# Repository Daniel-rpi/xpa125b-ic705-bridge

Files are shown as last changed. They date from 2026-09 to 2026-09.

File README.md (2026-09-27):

# IC-705 ↔ Xiegu XPA125B via TTGO Bluetooth-Bridge

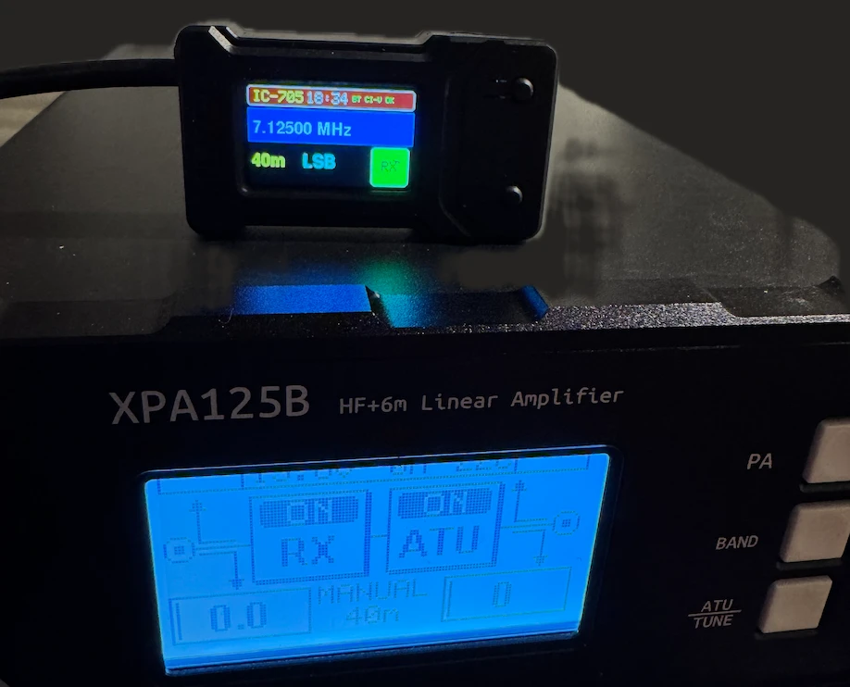
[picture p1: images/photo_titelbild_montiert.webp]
Fertiges Modul auf der XPA125B


Ein LilyGO **TTGO T-Display v1.1** (ESP32) verbindet sich per **Bluetooth
Classic (CI-V-over-SPP)** mit einem Icom **IC-705** und steuert darüber eine
nachgeschaltete Xiegu **XPA125B**-Endstufe (100 W HF-Verstärker) vollautomatisch:
Bandumschaltung, PTT und – seit Kurzem – eine softwareseitige ALC-basierte
Schutzschaltung, die eingreift, bevor die PA in ihre eigene harte
Fehlerabschaltung läuft.

Kein Kabelsalat zwischen 705 und PA, kein manuelles Bandwechseln an der PA, und
eine grobe, aber wirksame Warnstufe vor Übersteuerung – bei einem Funkgerät, das
selbst gar keine passende ACC-Buchse für so eine PA hat.

*(English: An ESP32 board bridges an Icom IC-705 (Bluetooth CI-V) to a Xiegu
XPA125B HF amplifier — automatic band switching, PTT, and a software ALC-based
overdrive protection layer. See [docs/alc-protection.md](docs/alc-protection.md)
for a full English write-up of the protection logic.)*

## ⚠️ Sicherheitshinweise (bitte vor dem Nachbau lesen)

- **≥ 3,2 V am PTT-Eingang der XPA125B zerstört deren internen Prozessor
  dauerhaft** (laut offiziellem Handbuch). Der PTT-Ausgang des TTGO läuft daher
  ausschließlich über eine galvanische Trennung (Optokoppler bzw. MOSFET-gegen-GND,
  siehe unten) – niemals GPIO26 direkt an die PA anschließen.
- Diese Firmware sendet zur reinen Anzeige (Frequenz/Modus/TX-Status/Uhrzeit)
  **ausschließlich CI-V-Lesebefehle**. Echte Sende-Kommandos (Leistung setzen,
  Modus setzen, PTT) gibt es nur in der Tune-Sequenz (Taster) und der
  ALC-Schutzfunktion – beide sind im Quellcode ausführlich kommentiert.
- Alle hier beschriebenen Werte (Bandspannungen, PTT-Pegel, ALC-Schwellen) sind
  **an einem konkreten IC-705 und einer konkreten XPA125B gemessen**. Vor dem
  Anschließen an eigene Hardware selbst nachmessen, nicht blind übernehmen.
- Kein Ersatz für die Schutzabschaltung der PA selbst – nur eine zusätzliche,
  frühere Warnstufe.
- Nachbau/Nutzung auf eigene Verantwortung.

## Basiert auf / Danke an

Dieses Projekt wäre ohne die Vorarbeit von **DL1BZ** nicht in dieser Form
entstanden:

- [dl1bz/ESP32-IC705BT-PA](https://github.com/dl1bz/ESP32-IC705BT-PA) – das
  ursprüngliche Konzept (ESP32 + Bluetooth-CI-V + Optokoppler-PTT + PWM/RC-Band-
  spannung für eine XPA125B), inklusive Forks von
  [PE1OFO](https://github.com/PE1OFO/IC-705-BlueTooth-Controller) und
  [DK8HC](https://github.com/dk8hc/IC-705-BlueTooth-Controller).

**Wichtig, damit klar ist, was wovon abstammt:** Die hier veröffentlichte
Firmware ist ein **komplett eigenständig geschriebener Sketch** (kein Codeauszug
aus den obigen Repos, keine `CIVmasterLib`-Abhängigkeit) – die Übernahme betrifft
das **Konzept und einzelne kalibrierte Werte**: die Verdrahtung
GPIO26→PTT/GPIO27→Bandspannung, die Bandspannungstabelle aus dem Xiegu-Handbuch
und die daraus abgeleitete Lastkorrektur (`corrMv` in `firmware/bands.h`) sind
1:1 aus `z_userprog.ino` von DL1BZ übernommen. Alles Weitere (TFT-Anzeige,
Uhrzeit/UTC, Tune-Sequenz mit FB/NG-Bestätigung, ALC-Auslesung samt
Schutzschaltung, das komplette PMR-171-BLE-Modul, die Daughterboard-Platine) ist
eigene Arbeit dieses Projekts.

## Fotos

| Rückseite (fertiges Modul) | Draufsicht (fertiges Modul) | Innenansicht |
|---|---|---|
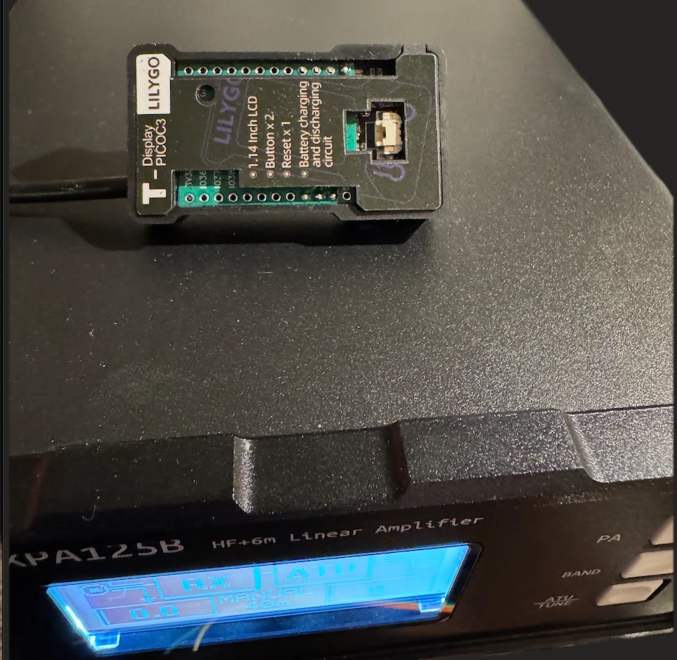
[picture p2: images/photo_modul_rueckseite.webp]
Rückseite des fertigen Moduls
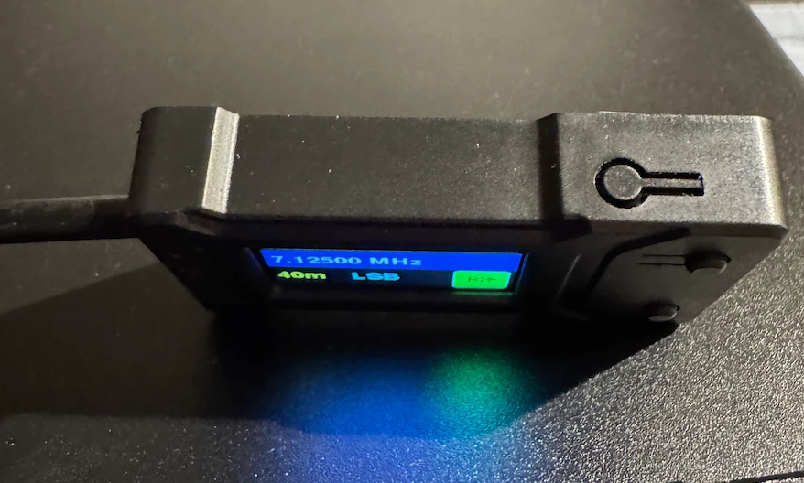
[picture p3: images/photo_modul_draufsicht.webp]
Draufsicht des fertigen Moduls
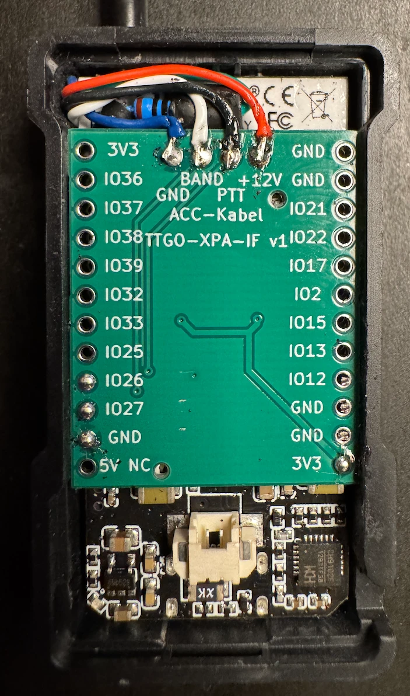
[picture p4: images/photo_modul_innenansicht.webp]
Innenansicht des fertigen Moduls
|  |  |  |

## Hardware

### Übersicht

```
IC-705 ──(Bluetooth Classic, CI-V-over-SPP)──> TTGO T-Display v1.1 (ESP32)
                                                     │  GPIO26 (PTT, über Opto/MOSFET gegen GND)
                                                     │  GPIO27 (PWM → RC 470Ω/22µF → Bandspannung)
                                                     │  GPIO36 (ADC, über 220Ω ← ALC-Ausgang, Pin 4)
                                                     ▼
                                        Xiegu XPA125B – ACC-Buchse (6-pol. Mini-DIN)
                                        Pin 1 = +12…14,5V (Versorgung der Platine) ⚠️ siehe unten
                                        Pin 2 = PTT (≥3,2V = Prozessorschaden!)
                                        Pin 3 = Bandspannung
                                        Pin 4 = ALC-Ausgang (~1–4V, invertiert)
                                        Pin 6 = GND
```

> **⚠️ ACC-Pin 1 ist im offiziellen Xiegu-Handbuch als N/C (nicht belegt)
> dokumentiert – liegt bei unserem (unmodifizierten, werksseitigen) Exemplar
> aber real die volle Versorgungsspannung der PA an** (gemessen ~12,85 V bei
> eingeschalteter PA am Netzteil, skaliert entsprechend mit der extern
> angelegten 12–14,5 V-Spannung). Genau das macht die eigene Stromversorgung
> des TTGO über die ACC-Buchse erst möglich, ohne ein zweites Netzteil oder
> einen Eingriff in die PA. Diese Diskrepanz zwischen Handbuch und Realität hat
> uns selbst lange beschäftigt (mehrere Diskussionsrunden, bis wir es am Ende
> direkt mit dem Multimeter durchgemessen haben) – **vor dem Nachbau unbedingt
> selbst am eigenen Gerät nachmessen**, statt sich auf das Handbuch *oder*
> diese Notiz zu verlassen. Xiegu könnte diese Pinbelegung in einer anderen
> Fertigungscharge/Hardwarerevision jederzeit ändern, ohne das zu
> dokumentieren – schließlich war sie nie offiziell zugesichert.

Das TTGO bezieht seine eigene 3,3-V-Versorgung direkt aus dieser
(inoffiziellen, aber real anliegenden) ACC-Pin-1-Spannung der PA (isolierter
DC/DC-Wandler bzw. Buck-Regler auf dem Daughterboard, siehe `hardware/`) –
**kein separates USB-Netzteil nötig, aber USB und PA-Strom dürfen nicht
gleichzeitig anliegen** (kein Akku auf der Platine, zwei Spannungsquellen
würden sich gegenseitig stören).

### Eigene SMD-Platine (Daughterboard)

Statt der Verkabelung frei fliegend aufzubauen: ein fertig geroutetes,
2-lagiges Daughterboard, das exakt auf die Stiftleisten des TTGO T-Display v1.1
gesteckt wird (Pin-Raster 1:1 aus der offiziellen LilyGO-Eagle-Bibliothek
übernommen), inkl. isoliertem Step-Down-Wandler, PTT-Schaltung und
RC-Filter für die Bandspannung.

- **[hardware/DESIGN.md](hardware/DESIGN.md)** – vollständige Bauteilliste,
  Netzliste, Layout-Vorgaben, Inbetriebnahme-Checkliste
- **[hardware/BESTELLUNG.md](hardware/BESTELLUNG.md)** – Schritt-für-Schritt
  JLCPCB-Bestellanleitung
- **`hardware/kicad/`** – fertig geroutetes KiCad-Projekt (DRC-geprüft)
- **`hardware/gerber/`** – Gerber + BOM + CPL, fertig für den JLCPCB-Upload
- **`images/`** – Renderansichten sowie reale Fotos des bestückten Boards

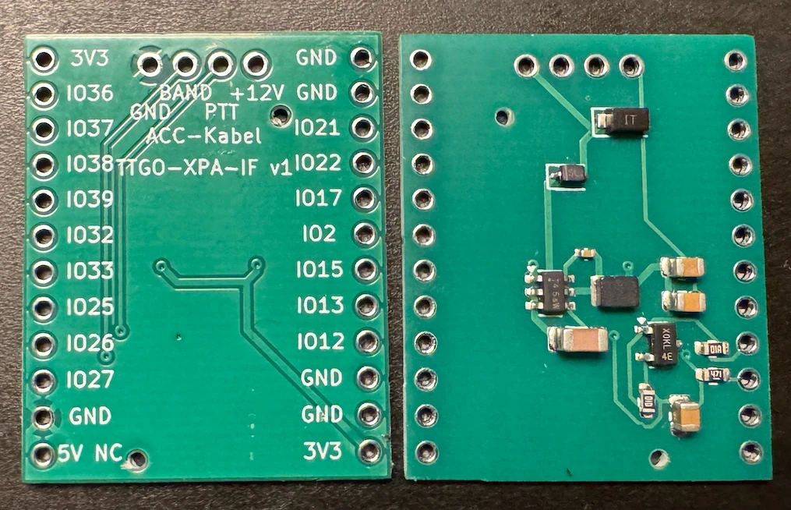
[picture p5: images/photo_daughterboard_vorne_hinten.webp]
Daughterboard: Vorder- und Rückseite


Die im finalen PCB-Entwurf verwendete PTT-Schaltung (N-MOSFET gegen GND) ist
eine bewusste, im Prototyp **nicht** getestete Vereinfachung gegenüber dem
ursprünglich verifizierten Optokoppler-Aufbau – Details und Begründung in
`hardware/DESIGN.md`. Der Optokoppler-Aufbau selbst ist am realen Gerät
vollständig getestet (siehe unten).

## Firmware

`firmware/ttgo_xpa_bridge.ino` (+ `bands.h`, `tft_setup.h`) – ein einziger
Arduino-Sketch für das TTGO T-Display v1.1 (Board-Definition:
`esp32:esp32:lilygo_t_display`, Arduino-ESP32-Core 3.x).

### Funktionen

- **Live-Anzeige** auf dem eingebauten TFT: Frequenz, Modulationsart, Band,
  RX/TX-Status, Uhrzeit (lokal + UTC, aus dem 705 ausgelesen), S-Meter.
- **Automatische Bandumschaltung** der XPA125B passend zur 705-Frequenz (PWM →
  RC-Tiefpass → Bandspannung, Tabelle inkl. Lastkorrektur in `bands.h`).
- **PTT-Durchschaltung** – der 705 meldet TX per CI-V-Broadcast/FastPTT-Push,
  das TTGO schaltet die PA-PTT-Leitung synchron mit.
- **Tune-Taster** (oberer Button, Mehrfachklick = längere Haltezeit): setzt
  kurzzeitig Leistung + Modus (FM statt CW – siehe Kommentar im Code, PTT-only
  erzeugt in CW keinen Träger), keyt den XPA125B-eigenen Antennentuner, stellt
  danach den Ausgangszustand wieder her. Jeder Schritt wartet auf eine
  FB(OK)/FA(NG)-Bestätigung; bei Fehlschlag Eskalation bis zur kompletten
  Geräteabschaltung (Cmd `18 00`).
- **ALC-Schutzschaltung** (neu, 2026-09-27) – siehe
  **[docs/alc-protection.md](docs/alc-protection.md)** für die volle
  Herleitung, Kalibrierdaten und Begründung, warum ein einfacher gleitender
  Mittelwert dafür nicht ausreicht.
- **Persistentes ALC/Leistungs-Logging** auf SPIFFS (überlebt den
  USB/PA-Stromwechsel, den ein reiner RAM-Puffer nicht überlebt hätte).
- **Zweiter Funkgeräte-Modus (PMR-171, Bluetooth LE)** – per langem Tastendruck
  umschaltbar (in NVS/`Preferences` persistiert). Eigenständiges Protokoll
  (BLE GATT statt Classic SPP), teilt sich aber Anzeige/GPIO-Grundgerüst mit dem
  705-Modus. Die ALC-Schutzschaltung ist **bewusst 705-spezifisch** und bleibt
  in diesem Modus inaktiv.
- **Automatischer Bluetooth-Reconnect**: das Board ist gleichzeitig
  BT-Server (nimmt Verbindungen vom 705 an) und -Master (verbindet sich aktiv
  zu bereits gekoppelten Geräten) – deckt sowohl "705 verbindet sich selbst"
  als auch "705 hat die Verbindung verloren, TTGO holt sie aktiv zurück" ab.

### Serial-Kommandos (USB, 115200 Baud, nur wenn USB angeschlossen – siehe
Sicherheitshinweis oben zur PA-Stromversorgung)

| Kommando | Wirkung |
|---|---|
| `dbg on` / `dbg off` | rohe CI-V-Frames auf der Konsole mitloggen |
| `fastptt on` | fastPTT-Push (`24 00 00 01`) aktivieren |
| `txpoll <ms>` | Poll-Intervall für den TX-Status |
| `band <name\|zero\|auto>` | Bandspannung manuell fixieren/automatisch |
| `alclog dump` / `clear` / `status` | ALC/Leistungs-Log (SPIFFS) auslesen/löschen/Status |
| `alcprotect on` / `off` | Schutzschaltung ohne Neuflashen de-/aktivieren |

### Flashen

```bash
arduino-cli core install esp32:esp32
arduino-cli compile --fqbn esp32:esp32:lilygo_t_display firmware/ttgo_xpa_bridge.ino
arduino-cli upload -p /dev/ttyXXX --fqbn esp32:esp32:lilygo_t_display firmware/ttgo_xpa_bridge.ino
```

Getestet mit Arduino-ESP32-Core 3.3.11.

## Status

- **Optokoppler-Prototyp (frei verdrahtet):** live an der echten XPA125B
  verifiziert – Bandumschaltung, PTT, Tune-Sequenz, ALC-Auslesung und die
  Schutzschaltung wurden alle mit echter Hardware getestet.
- **SMD-Daughterboard (MOSFET-Variante):** gefertigt, bestückt und am realen
  Gerät montiert (siehe Fotos oben) – zeigt live Frequenz/Modus/RX-Status vom
  705. Die PTT-Schaltung dieser Variante ist damit im Aufbau bestätigt; ein
  vollständiger, ausführlicher Sende-Test steht als Nächstes an (siehe
  `hardware/DESIGN.md`).
- **ALC-Schutzschaltung:** live getestet in FM (Kollapspunkt sauber erkannt)
  und SSB (vierstufige automatische Rückregelungs-Kaskade beobachtet, hat einen
  drohenden PA-Fehlerabschaltung erfolgreich verhindert).

## Lizenz

Eigener Code (Firmware, PCB-Design) unter [MIT-Lizenz](LICENSE). Die in
`firmware/bands.h` übernommene Bandspannungs-/Lastkorrekturtabelle stammt aus
DL1BZs `z_userprog.ino` (siehe Danke-Abschnitt) – bitte bei Weiterverwendung
dieser konkreten Werte entsprechend referenzieren.

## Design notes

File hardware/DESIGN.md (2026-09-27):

# TTGO ↔ XPA125B – SMD-Platine (Entwurfspaket für EasyEDA / JLCPCB)

Stand 2026-09-18. Grundlage: die **am 2026-09-18 an der echten XPA125B verifizierte** Prototyp-Schaltung
(4N25 + RC + isolierter DC/DC), ergänzt um zwei bewusste Änderungen (siehe „Abweichungen vom Prototyp").
Alle Teilenummern/Bestände/Gebührenklassen wurden am 2026-09-18 live gegen die JLC-Teiledatenbank
(jlcsearch.tscircuit.com, Felder `is_basic`/`is_preferred`/`stock`) geprüft – vor der Bestellung im JLC-Warenkorb
nochmal gegenchecken.

## Bauform (Nutzervorgabe 2026-09-18): Daughter-Board direkt auf den TTGO-Stiftleisten
Kleine Platine mit **genau dem Pin-Raster des TTGO T-Display v1.1** (2 Reihen à 12 Pins, 2,54 mm Raster, Reihenabstand
22,86 mm). Sie wird von hinten auf die Stiftleisten des TTGO gesteckt und auf der Außenseite verlötet - optisch ein eng
anliegendes Huckepack-Board. Maße/Koordinaten stammen aus der **offiziellen LilyGO-Eagle-Bibliothek**
(`TTGO-TDisplay_LilyGO_official.lbr`, Package `TTGO-T-DISPLAY-OL`), nicht aus Schätzungen:
- **Platine 25,89 × 31,94 mm** (0,4 mm je Seite breiter als der TTGO, damit die Pads ≥ 0,7 mm Randabstand haben - JLC trennt bei der
  Bestückung Randstreifen per V-Ritz und verlangt dafür ca. 0,4 mm; Länge = die 12 Pins + je 2,0 mm Rand), 0,8 mm, 2 Lagen.
- Pads: Bohrung 1,0 mm, **Pad-Ø 1,6 mm** (bei 1,78 mm läge der Kupferrand nur 0,22 mm von der Platinenkante, JLC will ≥ 0,3 mm;
  mit 1,6 mm sind es 0,31 mm).
- **Alle 24 Pads** liegen an den TTGO-Positionen (Tabelle in `ttgo_daughterboard_pads.csv`, Vorschau `board_preview.svg`).
  **Nur vier Pads sind mit der Schaltung verbunden**, alle anderen sind reine Lötaugen ohne Netz:

| TTGO-Pin | Reihe | Position (x / y in mm ab Platinen-Ecke unten links, USB-C-Ende unten) | Netz |
|---|---|---|---|
| 3V3 (`3V3_0`) | links | 1,11 / 2,00 | `3V3` (Ausgang des Bucks) |
| GND (`GND_4`) | rechts | 23,97 / 4,54 | `GND` |
| GPIO27 | rechts | 23,97 / 7,08 | `G27` (Bandspannung) |
| GPIO26 | rechts | 23,97 / 9,62 | `G26` (PTT) |
| **5V** | rechts | 23,97 / 2,00 | **NICHT verbinden** (direkt neben GND_4 - Kupfer-Abstand beachten) |

- **Alle vier Signalpads liegen in der rechten Reihe** dicht beieinander (y = 2,0 … 9,6), 3V3 gegenüber links unten.
- **Freie Zone für hohe Bauteile:** Mitte zwischen den Reihen, **y = 7,1 … 14,7 mm** (zwischen den Pads GPIO27 und GPIO33),
  x ≈ 4,2 … 20,9 mm. Auf dem Rückseitenfoto des TTGO ist genau dieser Bereich weitgehend unbestückt (Flash-IC ≈ 1,8 mm und
  die Tantal-Elkos sitzen an den Rändern/im USB-Bereich). Dorthin C1 (1206) und L1; niedrige Teile dürfen auch woanders hin.
- **J1 (ACC-Kabel)**: 4 Lötpads im 2,54-mm-Raster am Displayende der Platine, Vorschlag x = 8,74 / 11,28 / 13,82 / 16,36 bei
  y = 29,5 (Reihenfolge `+12V`, `PTT`, `BAND`, `GND` = ACC-Pin 1, 2, 3, 6). Die Kabel gehen so **nach oben weg, nicht am
  USB-C-Anschluss vorbei**.
- **Bestückungsseite = Richtung TTGO (Nutzerentscheidung 2026-09-18):** Stiftleisten-Kunststoffkörper sind „etwas mehr als 2,5 mm"
  hoch, das ist der Spalt zwischen TTGO-Rückseite und Board. Höhenbudget der Bauteile (Spalt 2,5 mm): C1 1206 ≈ 1,6 mm, U1/L1/D/Q1
  ≈ 1,0-1,1 mm, 0805 ≈ 1,25 mm, 0603/0402 < 1 mm. Auf der TTGO-Rückseite sind laut Produktfoto (mm-Raster über das Bild gelegt)
  **nur der Flash-IC (≈ 1,75 mm, Frontansicht x = 1,9-7,3 / y = 4,6-14,6 mm) und die Tantal-Elkos am USB-Ende (y < 2,2 mm)** hoch;
  dort sitzt kein Bauteil des Daughter-Boards. Der QFN (≈ 0,9 mm, x = 8,9-15,5 / y = 18,5-25 mm) und die Kleinteile bleiben unter
  1,25 + 0,9 < 2,5 mm. **Beim ersten Aufstecken trotzdem Probe-Sitz prüfen** (Foto-Ablesung ist eine Näherung).
- Aus den KiCad-Daten: Board wird auf der **Außenseite (B.Cu)** nur verlötet - dort GND-Fläche, PTT/BAND-Langstrecken, Beschriftung
  der TTGO-Pins (gespiegelt, damit sie von außen lesbar ist).

## ⚠ Der eine Punkt, der gegen „keine Aufpreis-Teile" läuft
Die 3,3-V-Versorgung aus den ~12,85 V der ACC-Pin-1 braucht einen **Schaltregler** (Linearregler würde ~1,2 W verheizen).
JLC führt **keine einzige Basic/Preferred-Leistungsdrossel** (nur mA-Signalinduktivitäten), und die freien Buck-Regler
(XL1509, TPS5430, TPS54331) sind Altbau-Typen mit Diode + Elektrolytkondensatoren – also weder flach noch ohne Extended-Drossel.
Deshalb: **2 Extended-Teile** (AP63203 + Drossel). Meines Wissens berechnet JLC dafür je eindeutigem Extended-Teil eine
einmalige Ladegebühr (ca. 3 USD pro Bestückungsauftrag) – im Warenkorb prüfen. Beide Teile sind stark lagernd
(11.392 bzw. 548.730 Stk.), also keine Sonderbestellware im Sinne von „nicht lieferbar".
Kostenfreie Alternative: keine gefunden, die auch flach ist (LDO = Hitzeproblem, siehe oben).

## ⚠️ ACC-Pin 1 ist im Handbuch als N/C dokumentiert, führt aber real Spannung
Das offizielle Xiegu-Handbuch listet ACC-Pin 1 der XPA125B als nicht belegt
(N/C). An unserem werksseitigen, unmodifizierten Exemplar liegt dort trotzdem
**real die Versorgungsspannung der PA an** (gemessen ~12,85 V bei
angeschlossenem Netzteil, skaliert mit dessen 12–14,5 V) - genau darauf baut
die gesamte Stromversorgung dieser Platine auf (`+12V_RAW` unten). Das war
kein Zufallsfund, sondern das Ergebnis einer längeren Diskussion und
letztlich einer direkten Multimeter-Messung. **Vor dem Nachbau am eigenen
Gerät selbst nachmessen** - eine andere Fertigungscharge/Hardwarerevision
könnte das jederzeit anders handhaben, da diese Belegung von Xiegu nie
zugesichert wurde.

## Schaltplan (Netzliste)
Netze: `+12V_RAW` (ACC-Pin 1, laut Handbuch N/C - siehe Warnhinweis oben), `+12V` (hinter D1), `3V3`, `GND`,
`SW`, `BST`, `PTT` (ACC-Pin 2), `BAND` (ACC-Pin 3), `G26`, `G27`, `GATE`.

| Bauteil | Anschlüsse |
|---|---|
| **J1** (4 Lötpads, ACC-Kabel) | 1=`+12V_RAW` (ACC-Pin 1), 2=`PTT` (Pin 2), 3=`BAND` (Pin 3), 4=`GND` (Pin 6) |
| **TTGO-Pads** (siehe oben) | `3V3` (links unten), `GND`, `G27`, `G26` (rechts) - kein separater Stecker J2 |
| D2 TVS SMF18CA | `+12V_RAW` ↔ `GND` |
| D1 1N5819WS | Anode `+12V_RAW`, Kathode `+12V` (Verpolschutz) |
| C1 10 µF/50 V | `+12V` ↔ `GND` (direkt an U1 Pin 3/4) |
| U1 AP63203WU-7 | Pin1 FB=`3V3`, Pin2 EN=`+12V`, Pin3 VIN=`+12V`, Pin4 GND=`GND`, Pin5 SW=`SW`, Pin6 BST=`BST` |
| C4 100 nF | `BST` ↔ `SW` |
| L1 4,7 µH | `SW` ↔ `3V3` |
| C2, C3 22 µF | `3V3` ↔ `GND` (je einer) |
| Q1 AO3400A | G=`GATE`, D=`PTT`, S=`GND` |
| R2 100 Ω | `G26` → `GATE` |
| R3 100 kΩ | `GATE` ↔ `GND` (hält PTT beim ESP32-Boot sicher aus) |
| R1 470 Ω | `G27` → `BAND` |
| C5 22 µF | `BAND` ↔ `GND` (direkt an J1.3 platzieren) |
| TP1–TP4 (Prüfpads, ohne BOM) | `3V3`, `+12V`, `BAND`, `PTT` |

Werte U1-Umfeld laut Diodes-Datenblatt DS41326, Tabelle 2 (AP63203, 3,3 V): L 3,9 µH (4,7 µH liegt im empfohlenen
Bereich 2,2–10 µH), C1 10 µF, C2 2×22 µF, C3 (BST) 100 nF, FB direkt an VOUT, EN darf an VIN (Abs.max 35 V, VIN 3,8–32 V).
RC-Filter 470 Ω/22 µF unverändert vom verifizierten Prototyp.

## Abweichungen vom verifizierten Prototyp (bewusst, bitte beachten)
1. **PTT-Schalter: N-MOSFET statt 4N25-Optokoppler.** Die Massen von TTGO und PA sind im Design ohnehin verbunden
   (für das Bandspannungssignal), der Optokoppler bringt also keine echte galvanische Trennung, ist aber das höchste Bauteil.
   AO3400A (48 mΩ @ 2,5 V Gate, SOT-23 ~1,1 mm) zieht PTT sauberer nach GND als die Opto-Sättigungsspannung.
   Sicherheit gleichwertig: der MOSFET kann die PTT-Leitung nur nach GND ziehen, nie Spannung einspeisen (Handbuch:
   ≥3,2 V am PTT-Pin zerstören die PA). **Auf dem Prototyp nicht getestet** – Firmware-Logik (GPIO26 HIGH = TX) bleibt identisch.
   Wer die verifizierte Topologie behalten will: LTV-357T (SOP-4 mini-flat) mit 220 Ω statt Q1/R2/R3 – sag Bescheid.
2. **Nicht isolierter Buck statt AM1G-1203SZ** – so bereits am 2026-09-13 entschieden (Isolation wegen der GND-Brücke
   sowieso nur „weich").

## Stückliste (JLCPCB-Format: `bom_jlcpcb.csv`)
| Ref | Wert | Package | LCSC | Klasse | Bestand |
|---|---|---|---|---|---|
| U1 | AP63203WU-7 (3,3 V, 2 A Buck) | TSOT-23-6 | C780769 | **Extended** | 11.392 |
| L1 | 4,7 µH, 2 A, 160 mΩ (FTC252010S4R7MBCA) | 1008 (2,5×2,0 mm) | C5832360 | **Extended** | 548.730 |
| Q1 | AO3400A N-MOSFET | SOT-23 | C20917 | Basic | 1.535.925 |
| D1 | 1N5819WS Schottky 40 V/1 A | SOD-323 | C191023 | Basic | 5.015.719 |
| D2 | SMF18CA TVS (bidirektional) | SOD-123FL | C19077513 | Preferred (gebührenfrei) | 398.632 |
| C1 | 10 µF/50 V X5R | 1206 | C13585 | Basic | 1.877.266 |
| C2, C3, C5 | 22 µF/25 V X5R | 0805 | C45783 | Basic | 1.734.789 |
| C4 | 100 nF/16 V X7R | 0402 | C1525 | Basic | 16.407.331 |
| R1 | 470 Ω 1 % | 0603 | C23179 | Basic | 1.899.614 |
| R2 | 100 Ω 1 % | 0603 | C22775 | Basic | 7.325.193 |
| R3 | 100 kΩ 1 % | 0603 | C25803 | Basic | 7.990.119 |

Einbauhöhe ca. 0,8 mm Platine + max. ~1,6 mm (C1) ≈ **2,4 mm gesamt**, sonst ≤ ~1,45 mm. Wer noch 0,3 mm will: C1 auf
10 µF/25 V 0805 (C15850) – 25 V liegt allerdings unter der TVS-Klemmspannung (29 V, nur µs-Impulse), daher Standard 50 V.

## Layout-Vorgaben (EasyEDA)
- **Zuerst die 24 TTGO-Pads exakt nach `ttgo_daughterboard_pads.csv` setzen** und die Platinenkontur (25,09 × 31,94 mm) zeichnen.
  Erst danach bestücken. Wer in EasyEDA lieber importiert: die mitgelieferte LilyGO-Eagle-Bibliothek enthält dieselben Pads.
- Nur die vier Netz-Pads (3V3, GND, G26, G27) verdrahten; die übrigen 20 Pads ohne Netz lassen (DRC-Warnung „unverbundenes
  Pad" ignorieren). Silkscreen an jedes Pad den TTGO-Pinnamen (Gegenprobe beim Aufstecken!). **5V-Pad: nicht verbinden**,
  Massefläche mit Abstand um dieses Pad herum freistellen.
- Unterseite (bzw. die Seite ohne Bauteile) als GND-Fläche, GND-Pad `GND_4` rechts unten anbinden.
- **Bauteilgruppen:** MOSFET Q1 + R1/R2/R3 + C5 direkt an den rechten Pads G26/G27/GND (y ≈ 4,5 … 10). Buck-Gruppe
  (U1, L1, C1–C4, D1, D2) in der Mitte bzw. darüber; **C1 und L1 in die freie Zone y = 7,1 … 14,7.**
- **U1-Umfeld eng:** C1 direkt an VIN/GND (Pin 3/4), L1 direkt an SW (Pin 5), C4 zwischen BST/SW, C2/C3 direkt hinter L1,
  SW-Fläche so klein wie möglich, GND-Vias neben C1/C2/C3. **BAND-Netz** (PWM-gefiltert) weit weg vom SW-Knoten,
  C5 unmittelbar am Pad G27-/J1-Zweig.
- J1-Beschriftung groß (`+12V`, `PTT`, `BAND`, `GND`) - ein Vertauschen an PTT ist der einzige teure Fehler.
- Prüfpads TP1–TP4 (1,0 mm) an den Rand, keine Montagebohrungen nötig (die Stiftleisten halten die Platine).
- Bauteile in EasyEDA über die **LCSC-Nummer** aus der BOM laden.

## JLCPCB-Bestelloptionen
PCB: 2 Lagen, 0,8 mm, HASL lead-free, Standard-Farbe. Bestückung: **Top only**, Standard-Bestückung; im Assembly-Schritt
prüfen, dass bei den Basic/Preferred-Teilen keine Extended-Gebühr angezeigt wird und bei U1/L1 genau zwei Gebühren stehen.
Drehwinkel/Polarität von U1 (Pin 1 Marker), D1, D2 und Q1 im Bestückungs-Viewer kontrollieren (häufigster Fehler).

## Inbetriebnahme (bevor die PA angeschlossen wird)
1. Noch ohne TTGO: nur J1.1 (+12 V) und GND mit dem Labornetzteil (12–14 V, Strombegrenzung 200 mA): TP `3V3` = 3,3 V ±3 %, Ruhestrom < 20 mA.
2. Platine auf die TTGO-Stiftleisten stecken (USB **nicht** gleichzeitig – der TTGO-LDO würde gegen den Buck arbeiten): bootet, verbindet sich.
3. Am 705 das Band wechseln: TP `BAND` = Handbuch-Sollwert +~3 % (ohne PA), z. B. 10m ≈ 2363 mV, 20m ≈ 1415 mV.
4. PTT drücken: `PTT`-Pad gegen GND im RX hochohmig, bei PTT nahezu 0 Ω (durchgeschalteter MOSFET), Rest wie im bisherigen PTT-Test.
5. Erst dann an die XPA125B; rote PTT-Ader vorher gegen GND messen (< 3,2 V!).

## Was ich nicht liefern kann (ehrlich)
Ich kann den EasyEDA-Editor nicht bedienen und habe **keine Gerber-/EasyEDA-Dateien erzeugt**. Der Entwurf ist die vollständige
Vorlage zum Nachzeichnen (Schaltplan ≈ 15 Min, Layout ≈ 30 Min); ich prüfe gern dein Ergebnis (Netzliste/BOM/Layout-Screenshot).

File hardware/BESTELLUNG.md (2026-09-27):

# Bestellung bei JLCPCB – Schritt für Schritt (Erstbesteller)

Stand 2026-09-18. Alle Fertigungsdaten liegen fertig in `fertigung/`:
- `ttgo_xpa_gerber.zip` – Platinendaten (Gerber + Bohrdaten), bei JLC bereits als **2 Lagen, 25,89 × 31,94 mm** erkannt
- `BOM_jlcpcb.csv` – Stückliste (LCSC-Nummern, 13 Bauteile in 11 Zeilen)
- `CPL_jlcpcb.csv` – Bestückungspositionen (Position + Drehung jedes Bauteils, alle „Top")

Der Bestell-Tab ist in deinem Browser bereits vorbereitet: Gerber hochgeladen, **0,8 mm, bleifreies HASL (Standard-Oberfläche), 5 Stück, Bestückung
Top-Seite, „Economic"**. Ich habe dort NICHTS bestätigt, kein Konto angelegt, nichts bezahlt und keine Bedingungen akzeptiert.

## Was du selbst tun musst
1. **Konto bei jlcpcb.com anlegen bzw. einloggen** (E-Mail + Passwort; Konto/Passwörter gibst du selbst ein).
2. Beim Bestücken: Häkchen **„I agree to the Terms and Conditions of JLCPCB assembly Service"** selbst setzen (Bedingungen kurz lesen).
3. **NEXT** klicken → Seite „Upload BOM & CPL": `BOM_jlcpcb.csv` und `CPL_jlcpcb.csv` hochladen
   (sag mir Bescheid, dann lade ich sie dir per Plugin hoch und lese das Ergebnis mit).
4. **Teile-Abgleich prüfen** (der wichtigste Schritt): Alle 13 Bauteile müssen „Matched" mit Lagerbestand sein. Erwartet:
   11 Positionen, davon **genau 2 Extended** (AP63203 = C780769, Drossel = C5832360) → dafür berechnet JLC eine Zusatzgebühr
   (meines Wissens ca. 3 USD je Extended-Teil, steht dort im Preis). Alles andere Basic/Preferred ohne Gebühr.
5. **Bestückungsvorschau prüfen** (2. Wichtigster Schritt; JLC dreht Bauteile manchmal anders als KiCad). Nur diese drei Teile sind
   drehungsempfindlich – so muss die **Draufsicht** aussehen (USB-C-Ende des TTGO = unten):
   | Teil | Richtig ist … |
   |---|---|
   | **U1** (AP63203, 6 Beine) | 3 Beine links, 3 rechts; **Pin 1 (Punkt/Marker) oben links** |
   | **Q1** (AO3400A, 3 Beine) | **2 Beine links, 1 Bein rechts** (das einzelne Bein rechts = Drain) |
   | **D1** (1N5819WS, Diode) | **Kathodenstrich links** |
   Alle anderen (Kondensatoren, Widerstände, Drossel, TVS-Diode D2 bidirektional) sind egal. Falsch gedreht → in JLCs Vorschau mit dem
   Drehknopf um 90° korrigieren (oder mir den Screenshot geben, ich sage dir den Winkel).
6. Zusammenfassung (Preis, Lieferadresse) prüfen, **Versandart wählen** (DHL ~28 USD ist die teuerste; günstigere Optionen wie
   „Global Standard Direct Line" dauern länger) und **bezahlen** (Zahlungsdaten gibst du selbst ein).

## Erwartete Kosten (grobe Einordnung, endgültig erst nach dem BOM-Upload)
PCB 5 Stück ≈ 4 USD + Oberfläche 1,1 USD, Bestückung/Bauteile/Extended-Gebühr kommen nach dem BOM-Upload dazu, Versand meist der größte Posten.
Mindestmenge sind 5 Platinen; du bekommst alle 5 bestückt (Ersatz für Fehlversuche).

## Wenn die Platinen da sind
1. TTGO-Stiftleisten (Kunststoffkörper > 2,5 mm) durch die Löcher des Daughter-Boards stecken, Board bündig auf die Kunststoffkörper
   drücken (Bauteile zeigen zum TTGO), auf der Außenseite verlöten. **USB nicht gleichzeitig, wenn das Board an der PA hängt.**
2. Inbetriebnahme wie in `DESIGN.md` („Inbetriebnahme"): erst Spannungen messen, dann TTGO, dann PA – mit der roten PTT-Ader
   vorher gegen GND messen (< 3,2 V!).
3. **PTT-Schalter ist jetzt ein MOSFET** (statt 4N25 im Prototyp) – erster Test an der PA mit wenig Leistung.

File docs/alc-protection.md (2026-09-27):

# ALC-Schutzschaltung (ALC protection)

*(English summary at the bottom of this document.)*

## Warum

Die XPA125B ist laut Datenblatt für 13 dB Gain / ≤5 W Ansteuerung / ≥110 W Ausgang
ausgelegt. Community-Berichte (und unsere eigenen Messungen) zeigen aber, dass der
Gain bei manchen Exemplaren deutlich außerhalb der Spezifikation liegt – schon
deutlich unter 1 W Ansteuerung kann nahezu die volle Ausgangsleistung anliegen.
Die PA hat einen eigenen harten Schutzabschalter (SWR/Übersteuerung), aber keine
abgestufte Warnung davor.

Wir haben **live am echten IC-705** geprüft, ob das Funkgerät selbst über sein
ALC-IN reagiert, wenn man das originale 705↔XPA125B-Rückführkabel ansteckt
(direkte Kabelverbindung, TTGO währenddessen nicht an der PA – beides geht wegen
gemeinsamer Buchse nicht gleichzeitig). Ergebnis: **keine native Regelung.** Das
Po-Meter folgt exakt der eingestellten Sendeleistung, unabhängig vom ALC-Meter-Wert
– sowohl in FM (bis 48 % Leistung getestet) als auch in SSB (Sprache + Pfeifton, bis
25–30 %). Die ALC-Regelung des 705 ist offenbar auf sein eigenes PA-Verhalten
ausgelegt, nicht auf ein externes ALC-Signal von einer nachgeschalteten PA.

**Folge:** Die einzige abgestufte, softwareseitige Schutzstufe zwischen "PA
arbeitet normal" und "PA schaltet hart ab" ist die hier beschriebene Funktion auf
dem TTGO. Sie ist **langsamer und gröber als eine echte ALC-Regelschleife**
(Abtastung alle 250 ms, Reaktion in festen Schritten, kein automatisches
Wiederhochfahren) – aber besser als nichts.

## Hardware

- XPA125B ACC-Pin 4 (ALC-Ausgang) → **220 Ω** in Reihe → TTGO GPIO36 (ADC1_CH0,
  input-only, kein Lötpad auf der Platine nötig – GPIO36 ist am T-Display v1.1
  ohnehin frei zugänglich).
- Gemessen (Multimeter, direkt an Pin 4 gegen Masse, echtes AliExpress-705↔XPA125B-
  Kabel mit durchverbundenem Pin 4): **RX ≈ 3,99 V, TX ≈ 1–2 V, durchgehend
  positiv, nie negativ.** Die genaue Bedeutung/Skalierung ist von Xiegu nicht
  dokumentiert – das Verhalten (hoch im Ruhezustand, sinkt beim Senden, sinkt
  weiter bei zunehmender Übersteuerung bis fast 0) deutet auf eine invertierte
  Aussteuerungsreserve-Anzeige hin.
- 3,99 V liegen ca. 0,4 V über der ESP32-ADC-Grenze (3,6 V absolut). Der 220-Ω-
  Widerstand begrenzt den Strom durch die interne Schutzdiode des GPIO-Pins
  (Klemmung bei ca. 3,9 V) auf < 0,5 mA – unbedenklich, kein zusätzliches Bauteil
  nötig.
- `analogSetAttenuation(ADC_11db)` für den vollen 0–3,3 V-Messbereich.

## Firmware-Logik (`ttgo_xpa_bridge.ino`)

### Persistentes Logging (für die Kalibrierung)

Die TTGO-Platine kann **nicht gleichzeitig per USB und von der PA versorgt
werden** (kein Akku, kein zweiter Spannungsregler-Pfad) – jedes Anstecken von USB
zum Auslesen der Messwerte reißt die Stromversorgung kurz ab und startet das
Board neu. Ein reiner RAM-Puffer für die Messreihen ist deshalb **garantiert
verlustanfällig**: genau das ist bei der allerersten Testreihe passiert – alle
Daten waren beim Wiederanstecken weg.

Fix: SPIFFS (Flash-Dateisystem). Während einer Sendung wird `ALC-Wert;
705-Sendeleistung (14 0A)` alle 250 ms in einen kleinen RAM-Zwischenpuffer
geschrieben und **erst nach TX-Ende** (oder bei einem ungewöhnlich langen Burst
vorsorglich schon währenddessen) als CSV-Block ans Flash angehängt – bewusst
nicht während jeder einzelnen Sendung, damit kein Flash-Schreibvorgang das
PTT-kritische Timing beeinflusst. Serial-Kommandos: `alclog dump` (ausgeben),
`alclog clear` (löschen), `alclog status`.

Alle Kalibrierdaten in diesem Dokument stammen aus genau diesen Dumps.

### Zwei Regelzweige, je nach Modulationsart

Ein fester Spannungsschwellwert allein funktioniert nicht für alle
Betriebsarten – ein Träger-Modus (FM) hat eine praktisch konstante ALC-Spannung
während der ganzen Sendung, ein Hüllkurven-Modus (SSB/CW) schwankt mit jedem Wort/
Atemzug zwischen weit auseinanderliegenden Werten. Die Firmware unterscheidet
deshalb:

```cpp
bool isConstantCarrierMode(uint8_t mode) {
  switch (mode) {
    case 0x02: case 0x04: case 0x05: case 0x06: case 0x08: case 0x17:
      return true;   // AM, RTTY, FM, WFM, RTTY-R, DV
    default:
      return false;  // LSB, USB, CW, CW-R → Hüllkurven-Modi
  }
}
```

**Konstanter Träger (FM/AM/RTTY/…):** einfaches Debounce. Fällt die ALC-Spannung
unter die Schwelle und bleibt dort für `ALC_PROTECT_FM_DEBOUNCE_MS` (750 ms),
gilt das als Übersteuerung.

**Hüllkurven-Modi (SSB/CW):** Hier hat sich der naheliegende Ansatz – ein
exponentiell gewichteter gleitender Mittelwert (EMA) über die ALC-Spannung – in
der Praxis als **grundlegend ungeeignet** erwiesen (siehe unten). Stattdessen ein
**Leaky-Bucket-Akkumulator** (asymmetrisch: schnell rauf, langsam runter):

```cpp
if (alcMv < ALC_PROTECT_THRESHOLD_MV) {
  alcProtectSsbAcc += ALC_PROTECT_SSB_ACC_INC;   // +1.0 pro 250-ms-Tick unter der Schwelle
} else {
  alcProtectSsbAcc -= ALC_PROTECT_SSB_ACC_DEC;   // -0.3 pro Tick darüber
}
// geclampt auf [0, ALC_PROTECT_SSB_ACC_CAP=20], ausgelöst ab ALC_PROTECT_SSB_ACC_TRIGGER=6.0
```

Warum das funktioniert, wo EMA scheitert: Eine echte Sprach-/Pfeifton-Übersteuerung
zeigt sich als **wiederkehrende kurze Unterschreitungen**, unterbrochen von
normalen Atempausen (in denen die ALC-Spannung kurz auf den Ruhewert ~3,1 V
zurückspringt). Ein EMA mit einem für schnelle Reaktion nötigen α wird durch
jede Atempause sofort wieder nach oben gezogen und erreicht den Schwellwert nie
zuverlässig – simuliert gegen eine echte 18-Sekunden-Aufnahme (durchgehend
lautes Pfeifen mit natürlichen Atempausen) blieb der EMA-Minimalwert bei
1107,5 mV, weit über der 500-mV-Schwelle, *obwohl* die reale Übersteuerung
während der gesamten Aufnahme präsent war. Der Leaky-Bucket dagegen **zählt
Ereignisse statt zu glätten**: jede Unterschreitung erhöht den Zähler stärker,
als eine kurze Pause ihn absenkt – bei anhaltender (auch intermittierender)
Übersteuerung akkumuliert er zuverlässig bis zum Trigger, an derselben
Testaufnahme simuliert: Auslösung nach 2,25 s.

### Reaktion

```cpp
int step = constantCarrier ? ALC_PROTECT_FM_STEP_RAW : ALC_PROTECT_SSB_STEP_RAW;
int newRaw = currentPowerRaw - step;
sendPowerSetRaw(newRaw);   // CI-V 14 0A, reiner Fire-and-forget-Write
```

- **Ein Schritt pro Auslösung**, kein Sprung auf einen festen Zielwert. `raw` ist
  0–255 (`14 0A`-Rohwert, 705-intern), FM-Schritt = 10 (~2 %), SSB-Schritt = 13
  (~5 %) – unterschiedlich kalibriert, weil sich der tatsächliche Auslösepunkt in
  Roheinheiten je nach Modus stark unterscheidet.
- **Cooldown 4 s** zwischen zwei Aktionen, damit nicht mehrfach hintereinander
  nachgeregelt wird, bevor sich der neue Zustand eingestellt hat.
- **Kein automatisches Wiederhochfahren** (bewusste Entscheidung) – der Bediener
  muss die Leistung nach einer Auslösung selbst wieder erhöhen. Sicherste
  Variante: die Software regelt nur nach unten, nie eigenständig nach oben.
- **Fire-and-forget statt blockierendem FB/NG-Handshake** (anders als die
  Tune-Sequenz an anderer Stelle im selben Sketch) – ein automatischer
  Schutzeingriff darf den Hauptloop/die PTT-Failsafe-Prüfung während einer
  laufenden Sendung nicht aufhalten. Schlägt der Schreibvorgang unbemerkt fehl,
  ist man dadurch nicht schlechter gestellt als vorher; die Reduktion wird beim
  nächsten Auslösen einfach erneut versucht.
- Deaktivierbar zur Laufzeit über die USB-Serielle: `alcprotect off` / `alcprotect on`
  (Default: an) – falls sich während eines Tests etwas unerwartet verhält, ohne
  neu flashen zu müssen.
- Reine 705-Funktion – im (davon unabhängigen) PMR-171-BLE-Modus derselben
  Firmware bleibt sie inaktiv.

## Kalibrierdaten (reale Messungen, 2026-09-27)

### FM-Sweep, 1 % → 21 % (bei angeschlossener PA)

| Leistung (raw / %) | ALC (mV) | Beobachtung |
|---|---|---|
| 3 / 1,2 % … 13 / 5,1 % | 2700–3118 | normal, keine Übersteuerung |
| 16 / 6,3 % | fällt von 2009 → 142 innerhalb 1 s | **PA-eigener Kollaps beginnt hier** |
| 18 / 7,1 % | bleibt bei ~142–190 | PA bereits im Fehlerzustand |
| 21 / 8,2 % | ~147–150, dann PA schaltet ab | harter Schutzabschalter der PA |

→ Der reale PA-Kollaps liegt konstant bei **raw = 16** (unabhängig vom
Testdurchlauf, mehrfach reproduziert) – siehe auch die Test-CSV im Repo
(`alcprotect_test_2026-09-27.csv` als Referenz, nicht mit veröffentlicht, da reine
Rohmessdaten ohne zusätzlichen Erkenntniswert über diese Tabelle hinaus).

### SSB, sustained lautes Pfeifen bis 35 %

PA schaltet bei ca. **raw = 90 (35 %)** ab. Mit dem finalen Leaky-Bucket-Ansatz
live bestätigt: **vierstufige automatische Rückregelungs-Kaskade**
90 → 77 → 64 → 51 → 38 (raw), die sich auf einen stabilen, crash-freien
Arbeitspunkt einschwang, ohne dass die PA nochmal in den Fehlerzustand ging.

## Bekannte Grenzen (ehrlich)

- Kein automatisches Wiederhochfahren – reine Schutzfunktion, kein
  Leistungsoptimierer.
- Reaktionszeit ~250 ms–4 s, je nach Modus/Debounce/Cooldown – eine echte
  Hardware-ALC-Schleife ist um Größenordnungen schneller. Für einen harten,
  plötzlichen Fehlanpassungsfall (z. B. offene Antenne) ersetzt diese Funktion
  **nicht** die PA-eigene Schutzabschaltung, sie ergänzt sie nur um eine
  frühere, sanftere Warnstufe.
- Die SSB-Schrittgröße (13/~5 %) ist bislang **ohne eigene reale
  Auslöse-Rückmeldung** kalibriert (der 35 %-Test hat die Kaskade ausgelöst und
  bestätigt, dass sie konvergiert – aber der exakt optimale Schrittwert wurde
  nicht gegen mehrere unabhängige SSB-Übersteuerungs-Ereignisse durchgemessen).
- Kalibriert an **einem konkreten Exemplar** der XPA125B – der PA-Kollapspunkt
  (raw=16 im FM-Test) kann bei einem anderen Gerät abweichen.

## English summary

The XPA125B's own gain can be so far out of spec that near-full RF output
appears at well under 1 W of drive. We confirmed live on a real IC-705 that the
radio's own ALC input does **not** self-regulate transmit power when the direct
705↔XPA125B ALC feedback cable is used (Po-meter tracks the dial power setting
regardless of ALC-meter reading, both in FM and SSB) — so a software safety net
on the TTGO bridge is genuinely needed, not redundant.

We tap the PA's own ALC output (ACC pin 4) through a 220 Ω series resistor into
ESP32 GPIO36 (ADC1_CH0). For constant-carrier modes (FM/AM/RTTY/…) a simple
debounced threshold is sufficient. For envelope modes (SSB/CW) an exponential
moving average turned out to be fundamentally unsuited — verified by simulating
it against real recorded data, where sustained-but-intermittent overdrive (real
speech/whistle bursts separated by breathing pauses) never pulled the average
below threshold even though the danger was continuously present. We replaced it
with an asymmetric leaky-bucket accumulator (fast rise on overdrive, slow decay
on recovery), which correctly triggered a 4-step automatic power-reduction
cascade (90→77→64→51→38 raw units) that converged to a stable, crash-free
operating point in a live SSB test. Every threshold/step value here was derived
from actual serial-logged test data (persisted to SPIFFS flash, since the board
cannot be powered by USB and the PA at the same time to retrieve a RAM-only log),
never from theory alone.

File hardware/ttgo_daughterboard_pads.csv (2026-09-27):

eagle_pad | pin | reihe | eagle_x_mm | eagle_y_mm | board_x_mm | board_y_mm | netz | hinweis
3V3_0 | 3V3_0 | links | 1.11 | 16.01 | 1.11 | 2.00 | 3V3 | MIT SCHALTUNG VERBUNDEN
GND_3 | GND_3 | links | 1.11 | 18.55 | 1.11 | 4.54 |  | nur Loetauge (kein Netz)
GND_2 | GND_2 | links | 1.11 | 21.09 | 1.11 | 7.08 |  | nur Loetauge (kein Netz)
12-G12-A15 | GPIO12 | links | 1.11 | 23.63 | 1.11 | 9.62 |  | nur Loetauge (kein Netz)
13-G13-A14 | GPIO13 | links | 1.11 | 26.17 | 1.11 | 12.16 |  | nur Loetauge (kein Netz)
15-G15-A13 | GPIO15 | links | 1.11 | 28.71 | 1.11 | 14.70 |  | nur Loetauge (kein Netz)
2-G2-A12 | GPIO2 | links | 1.11 | 31.25 | 1.11 | 17.24 |  | nur Loetauge (kein Netz)
17-DIONLY | GPIO17 | links | 1.11 | 33.79 | 1.11 | 19.78 |  | nur Loetauge (kein Netz)
22-SCL | GPIO22 | links | 1.11 | 36.33 | 1.11 | 22.32 |  | nur Loetauge (kein Netz)
21-SDA | GPIO21 | links | 1.11 | 38.87 | 1.11 | 24.86 |  | nur Loetauge (kein Netz)
GND_1 | GND_1 | links | 1.11 | 41.41 | 1.11 | 27.40 |  | nur Loetauge (kein Netz)
GND_0 | GND_0 | links | 1.11 | 43.95 | 1.11 | 29.94 |  | nur Loetauge (kein Netz)
5V | 5V | rechts | 23.97 | 16.01 | 23.97 | 2.00 |  | NICHT VERBINDEN (5 V vom TTGO/USB)
GND_4 | GND_4 | rechts | 23.97 | 18.55 | 23.97 | 4.54 | GND | MIT SCHALTUNG VERBUNDEN
27-G27-A17 | GPIO27 | rechts | 23.97 | 21.09 | 23.97 | 7.08 | G27 | MIT SCHALTUNG VERBUNDEN
26-G26-A19-DAC2 | GPIO26 | rechts | 23.97 | 23.63 | 23.97 | 9.62 | G26 | MIT SCHALTUNG VERBUNDEN
25-G25-A18-DAC1 | GPIO25 | rechts | 23.97 | 26.17 | 23.97 | 12.16 |  | nur Loetauge (kein Netz)
33-G33-A5 | GPIO33 | rechts | 23.97 | 28.71 | 23.97 | 14.70 |  | nur Loetauge (kein Netz)
32-G32-A4 | GPIO32 | rechts | 23.97 | 31.25 | 23.97 | 17.24 |  | nur Loetauge (kein Netz)
SVN-G39-A3 | GPIO39 | rechts | 23.97 | 33.79 | 23.97 | 19.78 |  | nur Loetauge (kein Netz)
38-G38 | GPIO38 | rechts | 23.97 | 36.33 | 23.97 | 22.32 |  | nur Loetauge (kein Netz)
37-G37 | GPIO37 | rechts | 23.97 | 38.87 | 23.97 | 24.86 |  | nur Loetauge (kein Netz)
SVP-G36-A0 | GPIO36 | rechts | 23.97 | 41.41 | 23.97 | 27.40 |  | nur Loetauge (kein Netz)
3V3_1 | 3V3_1 | rechts | 23.97 | 43.95 | 23.97 | 29.94 |  | nur Loetauge (kein Netz)

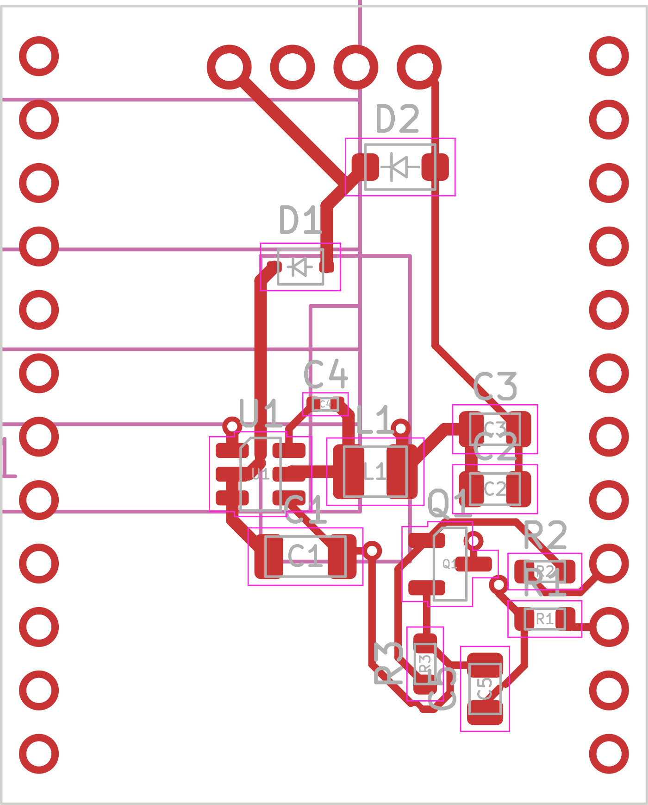
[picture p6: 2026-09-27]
images/vorschau_1_bestueckungsseite_mit_bauteilnamen.png

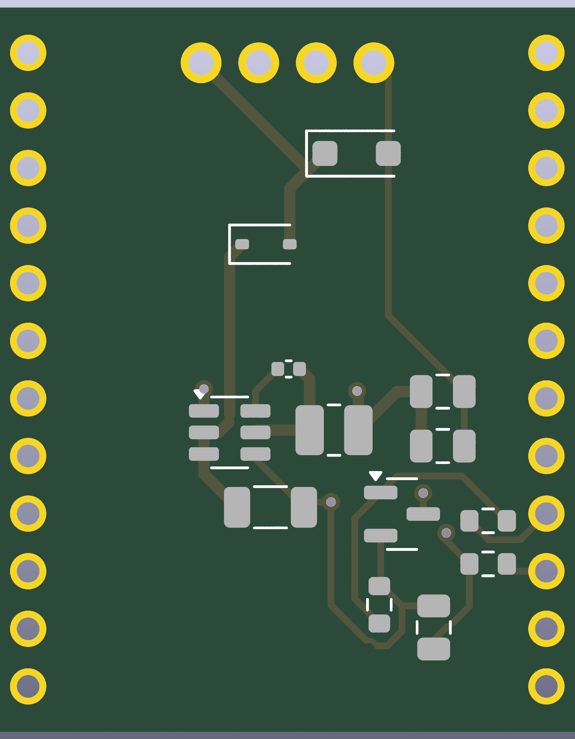
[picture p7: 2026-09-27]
images/render_top.png

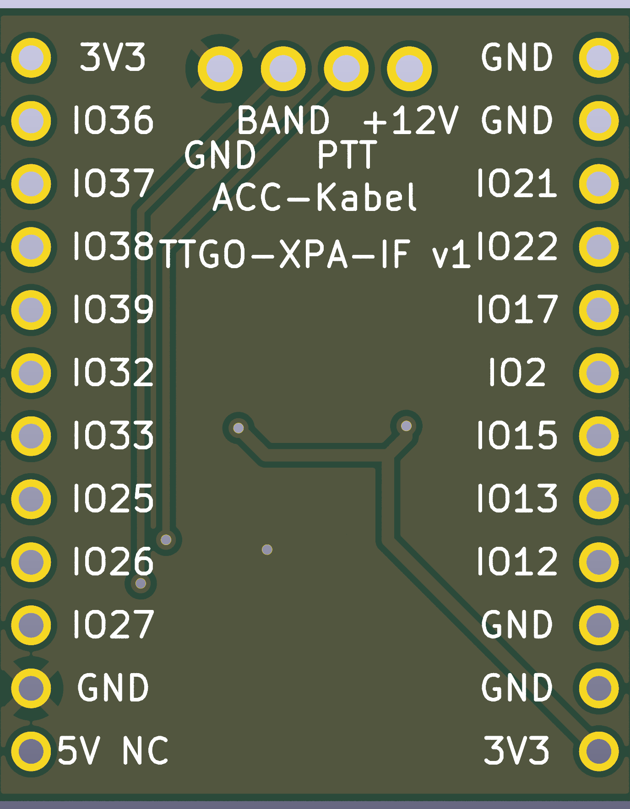
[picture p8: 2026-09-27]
images/render_bottom.png

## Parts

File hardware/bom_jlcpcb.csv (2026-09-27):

Comment | Designator | Footprint | LCSC Part #
AP63203WU-7 | U1 | TSOT-23-6 | C780769
FTC252010S4R7MBCA 4.7uH | L1 | L1008 | C5832360
AO3400A | Q1 | SOT-23 | C20917
1N5819WS | D1 | SOD-323 | C191023
SMF18CA | D2 | SOD-123FL | C19077513
10uF 50V X5R | C1 | C1206 | C13585
22uF 25V X5R | C2,C3,C5 | C0805 | C45783
100nF 16V X7R | C4 | C0402 | C1525
470R | R1 | R0603 | C23179
100R | R2 | R0603 | C22775
100k | R3 | R0603 | C25803

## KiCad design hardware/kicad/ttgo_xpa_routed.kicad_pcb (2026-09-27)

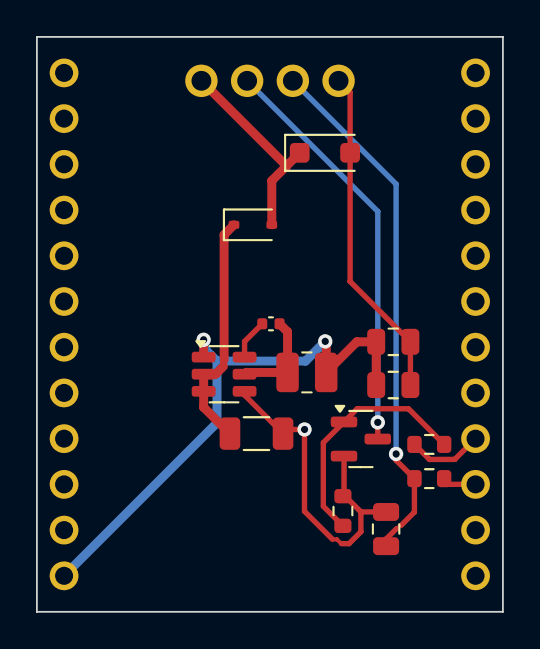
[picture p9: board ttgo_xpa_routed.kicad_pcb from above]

Board: 2 copper layers, 25.9 x 31.9 mm, 15 parts (0 on the bottom side), 11 nets.

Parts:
C1: 10uF/50V; C_1206_3216Metric
C2, C3, C5: 22uF/25V; C_0805_2012Metric
C4: 100nF; C_0402_1005Metric
D1: 1N5819WS; D_SOD-323
D2: SMF18CA; D_SOD-123F
J1: ACC-Kabel
J2: TTGO-Header-24
L1: 4.7uH; L_1008_2520Metric
Q1: AO3400A; SOT-23
R1: 470R; R_0603_1608Metric
R2: 100R; R_0603_1608Metric
R3: 100k; R_0603_1608Metric
U1: AP63203WU-7; TSOT-23-6

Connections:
3V3: C2.1, C3.1, J2.L1, L1.2, U1.1
+12V: C1.1, D1.1, U1.2, U1.3
+12V_RAW: D1.2, D2.1, J1.1
BAND: C5.1, J1.3, R1.1
BST: C4.1, U1.6
G26: J2.R4, R2.1
G27: J2.R3, R1.2
GATE: Q1.1, R2.2, R3.1
GND: C1.2, C2.2, C3.2, C5.2, D2.2, J1.4, J2.R2, Q1.2, R3.2, U1.4
PTT: J1.2, Q1.3
SW: C4.2, L1.1, U1.5

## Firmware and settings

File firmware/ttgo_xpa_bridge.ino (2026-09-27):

// TTGO T-Display v1.1 - Live-Anzeige fuer den IC-705 per Bluetooth CI-V,
// PLUS (seit 2026-09-11) ein Taster-ausgeloester Tune-Trigger fuer eine
// nachgeschaltete Xiegu XPA125B.
//
// SICHERHEIT: Die reine Anzeige (Frequenz/Modus/TX-Status/Uhrzeit/UTC-
// Offset) sendet weiterhin ausschliesslich reine CI-V-Lesebefehle (kein
// Datenbyte nach dem [Sub-]Kommando -> "Read", kein "Write").
//
// EINZIGE AUSNAHME: runTuneSequence() (ausgeloest durch den oberen Taster,
// GPIO35) sendet ECHTE Sende-Kommandos (Leistung setzen, Modus setzen,
// PTT ein/aus) - das ist die erste tatsaechliche TX-Aktion dieses Boards.
// Jeder einzelne Schritt wartet auf eine bestaetigte FB(OK)/FA(NG)-Antwort
// des Radios, bevor der naechste Schritt erfolgt (exakt dasselbe Muster
// wie band_sync.py auf raspberryhf fuer PTT nutzt). Schlaegt IRGENDEIN
// Schritt fehl/bleibt unbestaetigt, wird sofort auf PTT-AUS + Wieder-
// herstellung von Modus/Leistung eskaliert; bleibt selbst das erfolglos,
// wird als letzte Notbremse Cmd 18 00 (komplette Geraete-Abschaltung)
// gesendet - dieselbe staerkste verfuegbare Absicherung, die auch die
// bestehende 705-Notfall-Abschaltung auf dem homeassistant-Host nutzt.
// Ein fest verdrahteter Gesamt-Timeout (TUNE_SEQ_HARD_TIMEOUT_MS) schuetzt
// zusaetzlich gegen ein Haengenbleiben mitten in der Sequenz.
#include "tft_setup.h"
#include <TFT_eSPI.h>
#include "BluetoothSerial.h"
#include <BLEDevice.h>
#include <Preferences.h>
#include "bands.h"

TFT_eSPI tft = TFT_eSPI();
BluetoothSerial SerialBT;

// CI-V-Adressen (identisch zu band_sync.py auf raspberryhf)
const uint8_t RADIO_ADDR = 0xA4;   // feste CI-V-Werksadresse des IC-705
const uint8_t CTRL_ADDR  = 0xE0;   // Controller-/PC-Adresse

// Nur diese Byte-Folgen werden je gesendet - alle reine Lesebefehle
// (kein Datenbyte nach dem [Sub-]Kommando -> "Read", kein "Write").
// Uhrzeit/UTC-Offset laut offiziellem IC-705-CI-V-Referenzhandbuch:
// Cmd 1A 05, Sub-Sub-Kommando 0166 (Uhrzeit, lokal!) bzw. 0170 (UTC-
// Offset: Versatz-BCD + Richtung 00=+/01=-).
const uint8_t QUERY_FREQ[]       = {0xFE, 0xFE, RADIO_ADDR, CTRL_ADDR, 0x03, 0xFD};
const uint8_t QUERY_MODE[]       = {0xFE, 0xFE, RADIO_ADDR, CTRL_ADDR, 0x04, 0xFD};
const uint8_t QUERY_TX_STATUS[]  = {0xFE, 0xFE, RADIO_ADDR, CTRL_ADDR, 0x1C, 0x00, 0xFD};
const uint8_t QUERY_TIME[]       = {0xFE, 0xFE, RADIO_ADDR, CTRL_ADDR, 0x1A, 0x05, 0x01, 0x66, 0xFD};
const uint8_t QUERY_UTC_OFFSET[] = {0xFE, 0xFE, RADIO_ADDR, CTRL_ADDR, 0x1A, 0x05, 0x01, 0x70, 0xFD};
const uint8_t QUERY_POWER[]      = {0xFE, 0xFE, RADIO_ADDR, CTRL_ADDR, 0x14, 0x0A, 0xFD};
const uint8_t QUERY_SMETER[]     = {0xFE, 0xFE, RADIO_ADDR, CTRL_ADDR, 0x15, 0x02, 0xFD};
const uint8_t CMD_POWER_OFF[]    = {0xFE, 0xFE, RADIO_ADDR, CTRL_ADDR, 0x18, 0x00, 0xFD};

// --- Tune-Sequenz-Konstanten (2026-09-11, Nutzerwunsch + XPA125B-Handbuch
// Abschnitt 3.2.3 "Using the automatic antenna tuner unit"). ---
// WICHTIGE ANNAHME: 50% wird bewusst als externe-DC-Versorgung (705-Max
// 10W) angenommen -> 50% von 10W = 5W, exakt der vom Handbuch geforderte
// Wert. Laeuft der 705 stattdessen auf Akku (Max 5W), waere 50% nur 2,5W
// zu wenig fuers Tunen - der Sketch kann den aktuellen Stromversorgungs-
// Modus nicht per CI-V abfragen (keine etablierte/verifizierte Abfrage
// dafuer bekannt), daher bewusst als Annahme dokumentiert statt geraten.
const int TUNE_POWER_PERCENT = 50;
// FM statt CW (Nutzerfund 2026-09-11, live getestet): reines CI-V-PTT
// (Cmd 1C 00) erzeugt in CW-Betriebsart KEINEN Traeger - CW braucht ein
// echtes Keying-Signal, das PTT allein nicht liefert. FM erzeugt bei PTT
// dagegen automatisch einen vollen Traeger ohne weiteres Kommando - exakt
// dasselbe bereits bewaehrte Prinzip, das combo_tune_sequence() in
// band_sync.py auf raspberryhf fuer die SPE-Expert-PA-Tune-Sequenz nutzt
// ("705 kurz auf FM keyen"). Das XPA125B-Handbuch nennt zwar "CW" als
// Vorgabe, aber der eigentliche Bedarf ist nur ein stabiler Traeger zum
// Tunen - den liefert FM genauso zuverlaessig, ohne zusaetzliche Komplexitaet.
const uint8_t TUNE_MODE = 0x05;              // FM
const unsigned long TUNE_HOLD_MS = 3000;     // Basiswert PRO Klick (Nutzerwunsch: 1x=3s, 2x=6s, 3x=9s)
const unsigned long TUNE_ACK_TIMEOUT_MS = 2000;
const unsigned long TUNE_SEQ_HARD_TIMEOUT_MS = 20000;  // Notbremse fuer die GESAMTE Sequenz
const int TUNE_PTT_OFF_MAX_RETRIES = 5;

// ============================================================
// XPA125B-Ansteuerung (2026-09-18): Bandspannung (GPIO27) + PTT (GPIO26).
// Schaltplan 1:1 nach dl1bz/ESP32-IC705BT-PA, Pinbelegung der 4N25-Seite
// gegen das Vishay-Datenblatt korrigiert (siehe CLAUDE.md):
//   GPIO26 --[220R]--> 4N25 Pin1(Anode), Pin2(Kathode)=GND,
//          Pin5(Kollektor) -> ACC Pin2 (PTT, rot), Pin4(Emitter) -> ACC Pin6 (GND)
//   GPIO27 -> PWM 5 kHz/10 Bit -> RC 470R + 22uF -> ACC Pin3 (Bandspannung)
// ACHTUNG (XPA125B-Handbuch): >= 3,2 V am PTT-Pin zerstoert den Prozessor
// der PA dauerhaft - GPIO26 darf NIE direkt an die PA, nur ueber den Opto.
// ============================================================
const int PIN_PTT_OUT  = 26;   // HIGH = Optokoppler an = PTT der PA gegen GND (TX)
const int PIN_BAND_OUT = 27;   // PWM -> RC-Tiefpass -> Bandspannung

// ------------------------------------------------------------
// ALC-Einlesen (2026-09-27): PA-Pin4 (ALC-Ausgang der XPA125B) ueber einen
// 220-Ohm-Vorwiderstand an GPIO36 (ADC1_CH0, input-only, kein Loeten auf
// der Platine noetig, das Loetauge war schon frei). Gemessen (Multimeter,
// direkt an Pin4 gegen Masse): RX ~3,994V, TX ~1,x..2,x V, durchgehend
// positiv. 3,994V liegen ~0,4V ueber der ESP32-Grenze (3,6V absolut) -
// der 220-Ohm-Widerstand begrenzt den Strom durch die interne Schutzdiode
// (Klemmung bei ca. 3,9V) auf unter 0,5 mA, unbedenklich. Reiner Lesewert,
// KEINE Rueckwirkung auf PTT/Band/705-Sendeleistung in dieser Stufe.
// Vorwaertsdeklarationen fuer den ALC-Logger weiter unten - die echten
// Definitionen liegen erst deutlich spaeter im File (Anzeigezustand bzw.
// Tune-Sequenz-Tracking), werden hier aber schon gebraucht.
extern int txState;
extern int currentPowerRaw;
extern bool havePower;
extern uint8_t modeCode;
extern bool tuneRunning;
extern bool mode171;

const int PIN_ALC_ADC = 36;
const unsigned long ALC_READ_INTERVAL_MS = 250;
int alcMv = -1;              // -1 = noch keine Messung
unsigned long lastAlcReadMs = 0;
unsigned long lastAlcLogMs = 0;

// ------------------------------------------------------------
// ALC-Datenlogger (2026-09-27, Nutzerwunsch: fuer eine Kalibrierkurve
// "705-Sendeleistung -> ALC" nicht mehr vom Display abschreiben muessen).
// Puffert ALC (Pin4, GPIO36) + die per Cmd 14 0A abgefragte 705-Sende-
// leistung waehrend eines TX-Bursts zunaechst im RAM, schreibt den Burst
// aber IMMER erst NACH dessen Ende (TX 1->0, siehe handleFrame()) als
// Block in eine SPIFFS-Datei - bewusst NICHT waehrend des Sendens selbst,
// damit kein Flash-Schreibvorgang das PTT-kritische Timing stoeren kann.
//
// KORREKTUR (2026-09-27, echter eigener Fehler): die erste Version dieses
// Loggers hielt die Daten AUSSCHLIESSLICH im RAM - das ueberlebt aber
// KEINEN Stromausfall, und genau ein solcher tritt bei JEDEM Wechsel
// PA-Strom -> USB auf (die Platine hat keinen Akku, der die Luecke
// ueberbruecken koennte - siehe Kopfkommentar zum ALC-Einlesen oben).
// Ergebnis: die allererste Testreihe des Nutzers war komplett verloren,
// weil das Board beim Wiederanstecken an USB (zum Auslesen!) neu
// gestartet ist. Deshalb jetzt SPIFFS statt reinem RAM - der Flash
// uebersteht den Stromausfall, den RAM-Puffer NIE.
//
// Bewusst KEIN Live-Bluetooth-Relay zu raspberryhf (bräuchte eine zweite,
// parallele BT-Verbindung neben der PTT-kritischen 705-Verbindung,
// unerprobt, plus einen neuen BT-Server auf raspberryhf) - stattdessen:
// PA-Strom trennen, USB an raspberryhf anschliessen, per Serial-Kommando
// "alclog dump" komplett auslesen (uebersteht beliebig viele Bootzyklen
// dazwischen, da die Datei erst per "alclog clear" geloescht wird).
// Leistung ist ein reiner CI-V-LESEBEFEHL (14 0A ohne Datenbytes danach) -
// aendert nichts am Radio, passt zum bestehenden Sicherheitsmodell dieses
// Sketches.
// ------------------------------------------------------------
#include "FS.h"
#include "SPIFFS.h"

struct AlcLogEntry {
  unsigned long ms;
  int alcMv;
  int powerRaw;   // -1 = zum Zeitpunkt dieser Messung noch kein gueltiger Leistungswert bekannt
};
// Reicht als RAM-Zwischenpuffer fuer EINEN Burst (bei 250ms-Takt 500
// Eintraege = 125s) - deutlich mehr als ein typischer Testsendeknopfdruck
// braucht. Wird nahe der Kapazitaetsgrenze (ALC_LOG_FLUSH_THRESHOLD) auch
// schon WAEHREND einer unerwartet langen Sendung zwischengespeichert,
// damit nichts verloren geht - das ist der einzige Fall, in dem doch
// waehrend TX auf Flash geschrieben wird.
const int ALC_LOG_CAPACITY = 500;
const int ALC_LOG_FLUSH_THRESHOLD = 480;
AlcLogEntry alcLog[ALC_LOG_CAPACITY];
int alcLogCount = 0;

const char* ALC_LOG_PATH = "/alclog.csv";
bool spiffsOk = false;

// Nur waehrend TX abgefragt (siehe loop()) - haelt currentPowerRaw/havePower
// (bereits fuer die Tune-Sequenz vorhanden) fuer den Logger aktuell, ohne
// den PTT-kritischen Loop bei RX unnoetig mit zusaetzlichem BT-Traffic zu
// belasten.
const unsigned long POWER_QUERY_INTERVAL_MS = 500;
unsigned long lastPowerQueryMs = 0;

// Haengt den aktuellen RAM-Zwischenpuffer an die persistente Datei an und
// leert ihn danach. Wird am TX-Ende aufgerufen (normalfall, deutlich
// ausserhalb jeder Zeitkritik) sowie vorsorglich kurz vor dem Ueberlaufen
// eines ungewoehnlich langen Bursts (Ausnahmefall, siehe logAlcSample()).
void flushAlcLogToFile() {
  if (alcLogCount == 0) return;
  if (!spiffsOk) { alcLogCount = 0; return; }  // nichts zu retten, verwerfen statt haengenzubleiben
  fs::File f = SPIFFS.open(ALC_LOG_PATH, FILE_APPEND);
  if (!f) {
    Serial.println("ALCLOG: Datei zum Anhaengen oeffnen fehlgeschlagen - Burst verworfen");
    alcLogCount = 0;
    return;
  }
  for (int i = 0; i < alcLogCount; i++) {
    const AlcLogEntry& e = alcLog[i];
    if (e.powerRaw >= 0) {
      float pct = e.powerRaw * 100.0 / 255.0;
      float watts = e.powerRaw / 255.0 * 10.0;
      f.printf("%lu;%d;%d;%.1f;%.2f\n", e.ms, e.alcMv, e.powerRaw, pct, watts);
    } else {
      f.printf("%lu;%d;-1;-;-\n", e.ms, e.alcMv);
    }
  }
  f.close();
  alcLogCount = 0;
}

// Zusaetzliches periodisches Sicherheitsnetz (2026-09-27): faellt waehrend
// einer laufenden Sendung die Versorgung der Platine kurz aus (z.B. wenn die
// PA-eigene Schutzschaltung bei einem gezielten Grenztest die eigene
// Spannung mitbeeinflusst - genau das, was wir mit dem naechsten FM-Sweep-
// Test bewusst provozieren), wuerde ein reiner "nur am TX-Ende flushen"-
// Ansatz ausgerechnet den interessantesten, noch nicht geflushten letzten
// Sekundenbruchteil verlieren. Deshalb zusaetzlich alle ALC_LOG_TIME_FLUSH_MS
// ein Zwischen-Flush, unabhaengig vom eigentlichen Burst-Ende - begrenzt den
// maximalen Datenverlust bei einem unerwarteten Reset auf wenige Sekunden
// statt des gesamten Bursts. Reine SPIFFS-Schreiblast, beruehrt PTT/GPIO26
// nicht.
const unsigned long ALC_LOG_TIME_FLUSH_MS = 2000;
unsigned long lastAlcTimeFlushMs = 0;

void logAlcSample() {
  if (alcLogCount >= ALC_LOG_FLUSH_THRESHOLD) {
    flushAlcLogToFile();
  }
  if (alcLogCount >= ALC_LOG_CAPACITY) return;  // sollte durch den Threshold-Flush nie erreicht werden
  alcLog[alcLogCount].ms = millis();
  alcLog[alcLogCount].alcMv = alcMv;
  alcLog[alcLogCount].powerRaw = havePower ? currentPowerRaw : -1;
  alcLogCount++;
  if (millis() - lastAlcTimeFlushMs >= ALC_LOG_TIME_FLUSH_MS) {
    lastAlcTimeFlushMs = millis();
    flushAlcLogToFile();
  }
}

// Watt-Umrechnung nur eine Annahme (externe DC-Versorgung, 705-Max 10W -
// dieselbe bereits an anderer Stelle in diesem Sketch dokumentierte
// Annahme wie bei TUNE_POWER_PERCENT). Bei Akkubetrieb waeren es nur 5W.
// Steht bereits in jeder Zeile der Datei selbst (siehe flushAlcLogToFile()),
// dumpAlcLog() gibt die Datei nur unveraendert ueber Serial aus.
void dumpAlcLog() {
  flushAlcLogToFile();  // ein gerade laufender Burst soll im Dump miterscheinen
  if (!spiffsOk) { Serial.println("ALCLOG: SPIFFS nicht verfuegbar"); return; }
  if (!SPIFFS.exists(ALC_LOG_PATH)) {
    Serial.println("ALCLOG: keine Datei vorhanden (noch nichts geloggt)");
    return;
  }
  fs::File f = SPIFFS.open(ALC_LOG_PATH, FILE_READ);
  Serial.printf("ALCLOG: %u Byte in %s (ms;alc_mV;leistung_raw;leistung_pct;leistung_W_bei_10W_extern)\n",
                (unsigned)f.size(), ALC_LOG_PATH);
  uint8_t buf[256];
  while (f.available()) {
    size_t n = f.read(buf, sizeof(buf));
    Serial.write(buf, n);
  }
  f.close();
  Serial.println("ALCLOG: Ende");
}
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
void loop() {
  updateAlc();
  if (!mode171) while (SerialBT.available()) {
    feedByte((uint8_t)SerialBT.read());
  }

  // USB-Serial-Kommandos fuer den Bandspannungs-Bench-Test.
  while (Serial.available()) {
    char c = (char)Serial.read();
    if (c == '\n') {
      handleSerialCommand(serialLine);
      serialLine = "";
    } else if (c != '\r' && serialLine.length() < 40) {
      serialLine += c;
    }
  }
  if (bandTestOverride && (long)(millis() - bandTestUntil) >= 0) {
    Serial.println("BAND-TEST: 5 min abgelaufen, folge wieder der 705-Frequenz");
    bandTestOverride = false;
    appliedBandIdx = -2;
    if (haveFreq) updateBandVoltage(freqHz);
  }

  if (mode171) { loop171(); return; }
  if (digitalRead(BTN_GPIO0) == LOW && btn0PressStart && millis() - btn0PressStart >= SWITCH_HOLD_MS && lastBtn0State == LOW) { switchRadio(); }

  // Unterer Taster (GPIO0, per Nutzertest bestaetigt) = Display an/aus.
  // Oberer Taster (GPIO35) = Tune-Sequenz fuer die XPA125B.
  bool btn0 = digitalRead(BTN_GPIO0);
  bool btn35 = digitalRead(BTN_GPIO35);
  unsigned long nowMs = millis();
  if (nowMs - lastButtonMillis > BUTTON_DEBOUNCE_MS) {
    if (lastBtn0State == HIGH && btn0 == LOW) {
      // Druck-Beginn merken - Aktion erfolgt erst beim Loslassen, damit
      // zwischen kurz (Display-Toggle) und lang (Reconnect) unterschieden
      // werden kann.
      btn0PressStart = nowMs;
      lastButtonMillis = nowMs;
    } else if (lastBtn0State == LOW && btn0 == HIGH) {
      unsigned long heldMs = nowMs - btn0PressStart;
      lastButtonMillis = nowMs;
      if (heldMs >= LONG_PRESS_MS) {
        showSMeterView = !showSMeterView;
        // Kompletter Inhaltsbereich-Clear beim Umschalten (2026-09-11,
        // Nutzerfund): die Normalansicht raeumt nur ihre eigenen Teil-
        // bereiche frei (Frequenzbox + Band/Modus-Zeile bis x=176), deckt
        // aber nicht die volle Breite ab, die die S-Meter-Zeile bei ihrer
        // Schriftgroesse einnehmen kann - ohne diesen Clear blieben beim
        // Zurueckschalten Textreste am rechten Rand stehen.
        tft.fillRect(0, 30, tft.width(), tft.height() - 30, TFT_BLACK);
        screenDirty = true;
      } else {
        toggleDisplay();
      }
    } else if (lastBtn35State == HIGH && btn35 == LOW) {
      lastButtonMillis = nowMs;
      // Klick nur ZAEHLEN, nicht sofort ausloesen - siehe Auswertung
      // weiter unten nach Ablauf von MULTI_CLICK_WINDOW_MS.
      tuneClickCount++;
      lastTuneClickTime = nowMs;
    }
  }
  lastBtn0State = btn0;
  lastBtn35State = btn35;

  // Mehrfachklick-Auswertung: erst ausloesen, wenn eine Weile kein
  // weiterer Klick mehr kam (Nutzerwunsch: 1x=3s, 2x=6s, 3x(+)=9s).
  if (tuneClickCount > 0 && nowMs - lastTuneClickTime > MULTI_CLICK_WINDOW_MS) {
    int clicks = tuneClickCount;
    if (clicks > MAX_TUNE_CLICKS) clicks = MAX_TUNE_CLICKS;
    tuneClickCount = 0;
    if (SerialBT.hasClient()) {
      runTuneSequence((unsigned long)clicks * TUNE_HOLD_MS);
    }
  }

  bool nowConnected = SerialBT.hasClient();
  if (nowConnected != wasConnected) {
    Serial.printf("[%lums] Verbindungsstatus-Wechsel: %s\n", millis(), nowConnected ? "VERBUNDEN" : "GETRENNT");
    screenDirty = true;
    if (nowConnected) {
      // Frisch verbunden: fastPTT einschalten (das Radio setzt es beim
      // Ausschalten zurueck, Fussnote *7 im CI-V-Handbuch) und sofort
      // Frequenz/Modus holen, damit Band + PTT-Freigabe nicht 2 s warten.
      // Bewusst NUR hier einmal, nicht periodisch: die FB-Antwort geht
      // durch den generischen Ack-Mechanismus der Tune-Sequenz.
      SerialBT.write(CMD_FASTPTT_ON, sizeof(CMD_FASTPTT_ON));
      sendQuery(QUERY_FREQ, sizeof(QUERY_FREQ));
      sendQuery(QUERY_MODE, sizeof(QUERY_MODE));
      Serial.printf("[%lums] fastPTT (24 00 00 01) gesendet\n", millis());
    }
    if (!nowConnected) {
      setPtt(false, "BT getrennt");
      haveFreq = false;
      haveMode = false;
      txState = -1;
      haveUtcOffset = false;
      localMinutes = -1;
    }
  }

  // Einmaliger automatischer Reconnect-Versuch kurz nach dem Booten -
  // deckt sowohl "war kurz verbunden, dann Disconnect" (Nutzerbeobachtung)
  // als auch "nie verbunden gewesen" ab.
  // Per Zeitstempel-Log gemessen (2026-09-11): connect() selbst braucht
  // nur ~900ms - die urspruengliche 8s-Wartezeit war unnoetig vorsichtig
  // und sorgte fuer eine spuerbare, aber sinnlose Verzoegerung. 1,5s reicht
  // als Sicherheitsabstand, damit der BT-Stack nach begin() sicher bereit
  // ist, bevor wir selbst aktiv verbinden.
  if (!didBootReconnectAttempt && millis() - bootMillis < BOOT_RECONNECT_WINDOW_MS) {
    bool shouldTry = (!nowConnected && wasConnected) ||
                      (!nowConnected && millis() - bootMillis > 1500);
    if (shouldTry) {
      didBootReconnectAttempt = true;
      reconnectToRadio();
    }
  }

  wasConnected = nowConnected;

  // TX-Status und Uhrzeit werden JEDEN Takt (2s) abgefragt - der 705
  // meldet PTT-Wechsel ueber Bluetooth CI-V offenbar nicht zuverlaessig
  // von selbst per Broadcast, daher hier bewusst haeufig aktiv nachgefragt.
  // UTC-Offset aendert sich praktisch nie - nur einmalig pro Verbindung
  // nachfragen, bis eine Antwort da ist.
  if (nowConnected && !tuneRunning && millis() - lastQueryToggle > 2000) {
    lastQueryToggle = millis();
    sendQuery(QUERY_TX_STATUS, sizeof(QUERY_TX_STATUS));
    sendQuery(QUERY_TIME, sizeof(QUERY_TIME));
    if (showSMeterView) {
      sendQuery(QUERY_SMETER, sizeof(QUERY_SMETER));
    }
    if (!haveUtcOffset) {
      sendQuery(QUERY_UTC_OFFSET, sizeof(QUERY_UTC_OFFSET));
    }
    if (queryFreqNext) {
      sendQuery(QUERY_FREQ, sizeof(QUERY_FREQ));
    } else {
      sendQuery(QUERY_MODE, sizeof(QUERY_MODE));
    }
    queryFreqNext = !queryFreqNext;
  }

  pttFailsafeCheck(true);

  // Schnelles TX-Polling (Standard 100 ms, Rueckfallebene fuer PTT; per
  // "txpoll <ms>" aenderbar, "txpoll 0" = nur der 2-s-Takt).
  if (txPollMs > 0 && nowConnected && !tuneRunning && millis() - lastFastTxPoll >= txPollMs) {
    lastFastTxPoll = millis();
    sendQuery(QUERY_TX_STATUS, sizeof(QUERY_TX_STATUS));
  }

  // Fuer den ALC-Datenlogger (siehe oben): waehrend TX periodisch die
  // Sendeleistung nachfragen, damit jeder gepufferte ALC-Wert einen
  // moeglichst frischen Leistungswert dabei hat. Bewusst NUR waehrend TX -
  // bei RX interessiert der Wert fuer die Kalibrierkurve nicht, und es soll
  // kein unnoetiger BT-Traffic neben dem PTT-kritischen Polling entstehen.
  if (nowConnected && !tuneRunning && txState == 1 &&
      millis() - lastPowerQueryMs >= POWER_QUERY_INTERVAL_MS) {
    lastPowerQueryMs = millis();
    sendQuery(QUERY_POWER, sizeof(QUERY_POWER));
  }

  if (screenDirty) {
    render();
    screenDirty = false;
  }

  delay(txPollMs > 0 ? 1 : 10);
}

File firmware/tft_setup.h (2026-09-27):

// Eigenstaendige TFT_eSPI-Konfiguration fuer den TTGO T-Display v1.1 -
// direkt im Sketch definiert (1:1 aus der mitgelieferten
// User_Setups/Setup25_TTGO_T_Display.h uebernommen), damit KEINE
// Bibliotheksdatei angefasst werden muss (reproduzierbar, ueberlebt eine
// Neuinstallation der Bibliothek). Muss VOR jedem #include <TFT_eSPI.h>
// eingebunden werden.
#pragma once
#define USER_SETUP_LOADED 1

#define ST7789_DRIVER
#define TFT_SDA_READ

#define TFT_WIDTH  135
#define TFT_HEIGHT 240

#define CGRAM_OFFSET

#define TFT_MOSI 19
#define TFT_SCLK 18
#define TFT_CS   5
#define TFT_DC   16
#define TFT_RST  23

#define TFT_BL 4
#define TFT_BACKLIGHT_ON HIGH

#define LOAD_GLCD
#define LOAD_FONT2
#define LOAD_FONT4
#define LOAD_FONT6
#define LOAD_FONT7
#define LOAD_FONT8
#define LOAD_GFXFF

#define SMOOTH_FONT

#define SPI_FREQUENCY  40000000
#define SPI_READ_FREQUENCY  6000000

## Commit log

2026-09-27 Initial publish: IC-705 <-> Xiegu XPA125B TTGO Bluetooth bridge
    ESP32 (TTGO T-Display v1.1) board bridging an Icom IC-705 (Bluetooth
    Classic CI-V) to a Xiegu XPA125B amplifier: automatic band voltage
    switching, PTT passthrough, an auto-tune trigger sequence, and a
    software ALC-based overdrive protection layer (with full calibration
    data and reasoning in docs/alc-protection.md).
    Concept and band-voltage/load-correction table based on dl1bz's
    ESP32-IC705BT-PA (and its PE1OFO/DK8HC forks); firmware itself is an
    independent implementation with no shared code/library. Includes a
    finished, DRC-checked KiCad daughterboard design ready for JLCPCB.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
    [BOM_jlcpcb.csv, bom_jlcpcb.csv, ttgo_daughterboard_pads.csv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]
2026-09-27 Add real photos of the assembled unit and daughterboard
    Title photo (mounted on the XPA125B, live display), rear/top/inside
    views of the finished case, and a front/back shot of the assembled
    SMD daughterboard. Updated the status note: the MOSFET PTT variant is
    now confirmed built and running (display shows live frequency/mode/RX),
    full TX testing still pending.
2026-09-27 Document that ACC pin 1 carries supply voltage despite manual saying N/C
    The XPA125B manual documents ACC pin 1 as not connected, but on our
    unmodified factory unit it actually carries the amplifier's own supply
    rail (~12.85V, scales with the external 12-14.5V feed) - this is what
    the whole daughterboard's power supply relies on. Took considerable
    back-and-forth discussion and a direct multimeter measurement to
    confirm; flagged prominently in both README.md and hardware/DESIGN.md
    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
2026-09-27 Clarify: no Bluetooth MAC address is baked into the firmware
    Checked the whole firmware for any hardcoded MAC/BT address - there is
    none. reconnectToRadio() reads bonded devices at runtime from the
    ESP32's own on-chip bonding table (populated by pairing, stored in that
    board's flash), never from source code. Added a comment at that call
    site so future readers don't have to wonder/ask the same question.
